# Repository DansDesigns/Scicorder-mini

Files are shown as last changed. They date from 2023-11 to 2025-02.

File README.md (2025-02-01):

# Ultra-Slim-Tricorder
A multi sensor device based on ESP32, Inspired by Star Trek TNG Tricorder

NOTE, DUE TO TECHNICAL LIMITATIONS, THIS PROJECT HAS BEEN UPGRADED - SEE THE SCIO REPO

Youtube Development Channel:
https://www.youtube.com/channel/UC_F5HQEmCyoRnEubfEMa24g

No copyright infringment intended, this is purely an exercise in fun and an homage to some great Sci-Fi Technology!

Hardware:
```
ESP32-WROOM-32e
NS8002 Amplifier Module
8ohm 1Watt Speaker
Wireless Charging with internal TP4056 LiPo Charger
MPR121 12-Channel Capacitive Touch Sensor
Red/Green Power Status LED
Tricolour Status LED's

Integrated Sensors:
INMP441 I2S Mono Microphone
VL53L0X ToF Laser Distance Sensor
HMC5883L Magnetometer
BME280 Environmental Temperature, Humidity, Pressure & Altitude Sensor
SI1145 Visible Light, UV & IR Sensor
LTR-3900-UV UVA & UVB Sensor
TCS3200 RGB Colour Sensor
MPU6050 3-Axis Accelerometer, 3-Axis Gyroscope
  & Internal Temperature Sensor all-in-one
Magnetic Open-Close Lid Sensor
microSD Card Slot for Data Logging
Custom Dust/Particle Density Sensor

3D Printed Case featuring Electroplated Gold Capacitive Buttons & Highlights.
```

## Hardware Setup
```

```

## Code & Libraries
```

Arduino Tones library is used to generate the different notification sounds.

Capacitive Touch is powered by the MPR121 chip aswell as using the ESP32's onboard Capacitive Touch Pins

I2S Microphone Streaming was modified from here:
- https://github.com/pschatzmann/arduino-audio-tools/tree/main

Wifi Manager was taken from here:
- https://github.com/ozbotics/WIFIMANAGER-ESP32/tree/master

OTA Updater modified from:
- https://www.youtube.com/watch?v=o4Qw0CDzO7E

```

## Installation
```
If building yourself, Flash the OTA_Installer.ino to the ESP32 via Arduino IDE.

On reboot the OTA Updater will search GitHub for the latest Release,
it automatically Downloads, Installs and Reboots the Tricorder.

Wifi will then need to be setup again by using the Setup_AP Function.
- RETAIN SSID BETWEEN UPDATES - WIP

Manual checking for update is possible by typing "U" into the Serial Monitor.

If need to change WIFI SSID, press the WIFI Button and connect to the
"Setup_AP" WIFI Access Point from a wifi enabled device, following the on screen instructions.
```

## Usage
```

```

## ToDo
```
WIP = In Progress, TBS = To Be Started , TBD = To Be Decided, R&D = Research needed

- Make simple OTA_Installer.ino starter file to run OTA updater, pulling latest Release to flash full working code. - DONE
- Finish this ReadMe..

```

```
## Contributing

Pull requests are welcome. For major changes, please open an issue first
to discuss what you would like to change.

Please make sure to update tests as appropriate.

```

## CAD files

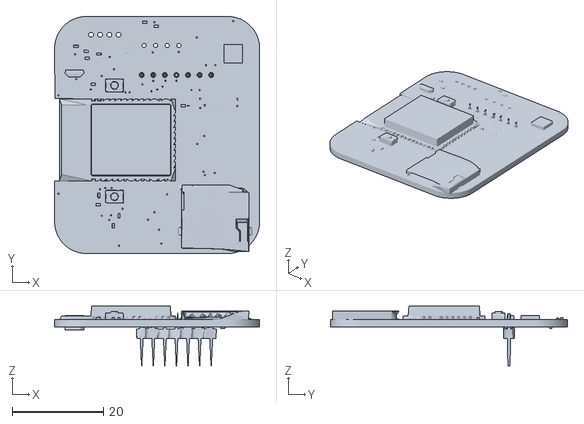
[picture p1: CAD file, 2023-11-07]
!_Prototype PCB 3D Files_!/UST-Main-Board.stl
45.0 x 52.0 x 13.1

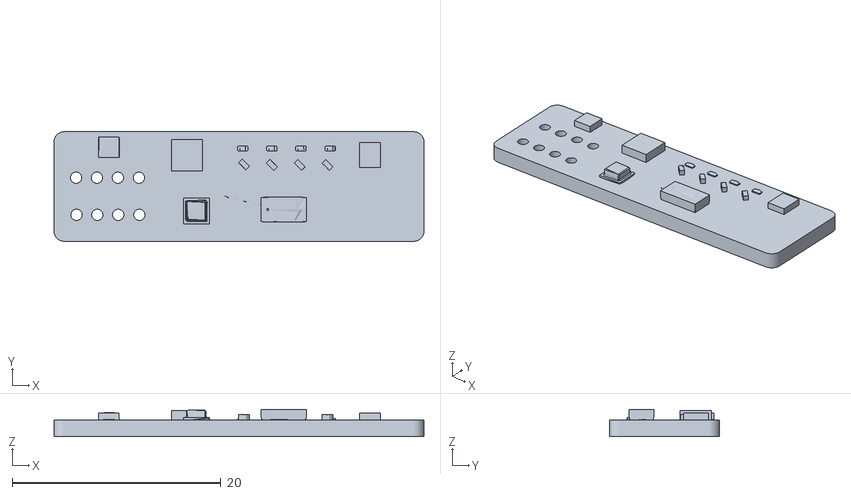
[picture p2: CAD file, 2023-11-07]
!_Prototype PCB 3D Files_!/UST-Sensor-Board.stl
35.5 x 10.5 x 2.61

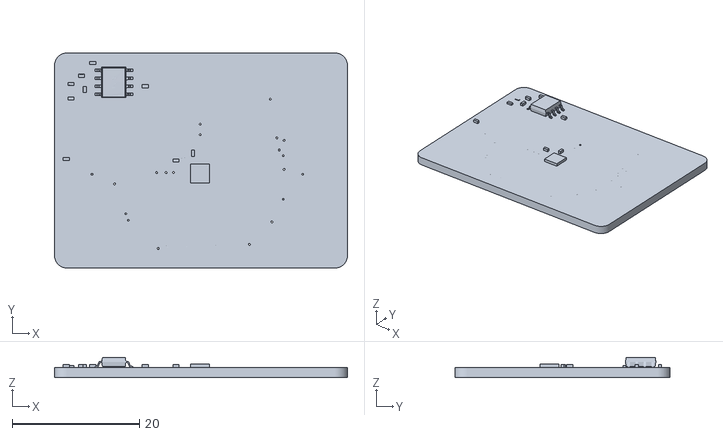
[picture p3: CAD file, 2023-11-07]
!_Prototype PCB 3D Files_!/UST-Battery_Input-Board.stl
46.1 x 33.9 x 3.22

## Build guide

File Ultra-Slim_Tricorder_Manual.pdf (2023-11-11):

# Ultra-Slim Tricorder

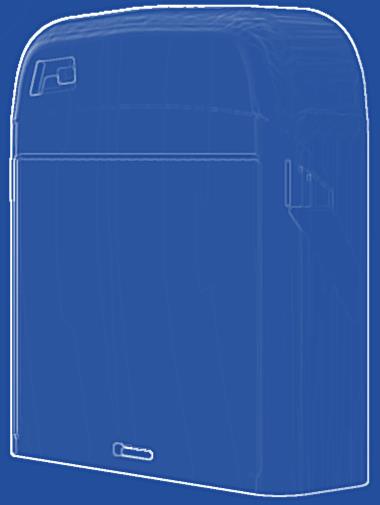
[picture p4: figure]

### DansDesigns

V0.1a

Sensor Board

Capacitive TouchPad
& Power

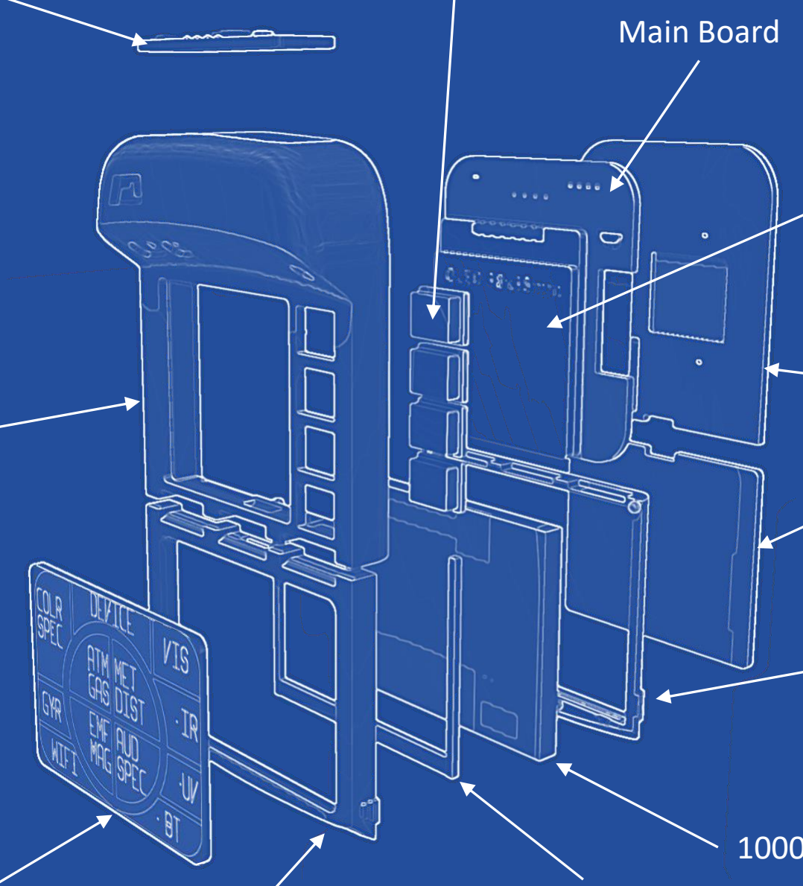
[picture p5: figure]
Main Board

Management Board | TouchPad Bracket

1000mAh LiPo

Lower Body
Rear Section

Lower Body
Forward Section

Upper Body
Main Section

1.5” Full
Colour OLED

Rear Covers

Capacitive Touch Buttons

# Exploded View

54.7mm

# Dimensions

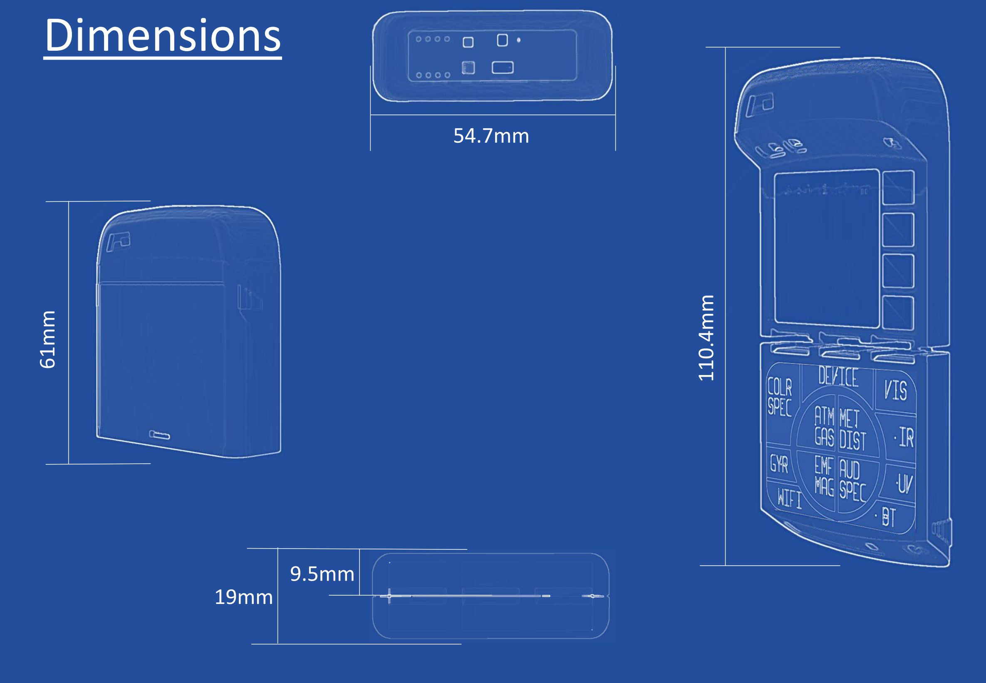
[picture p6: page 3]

19mm

61mm

9.5mm

110.4mm

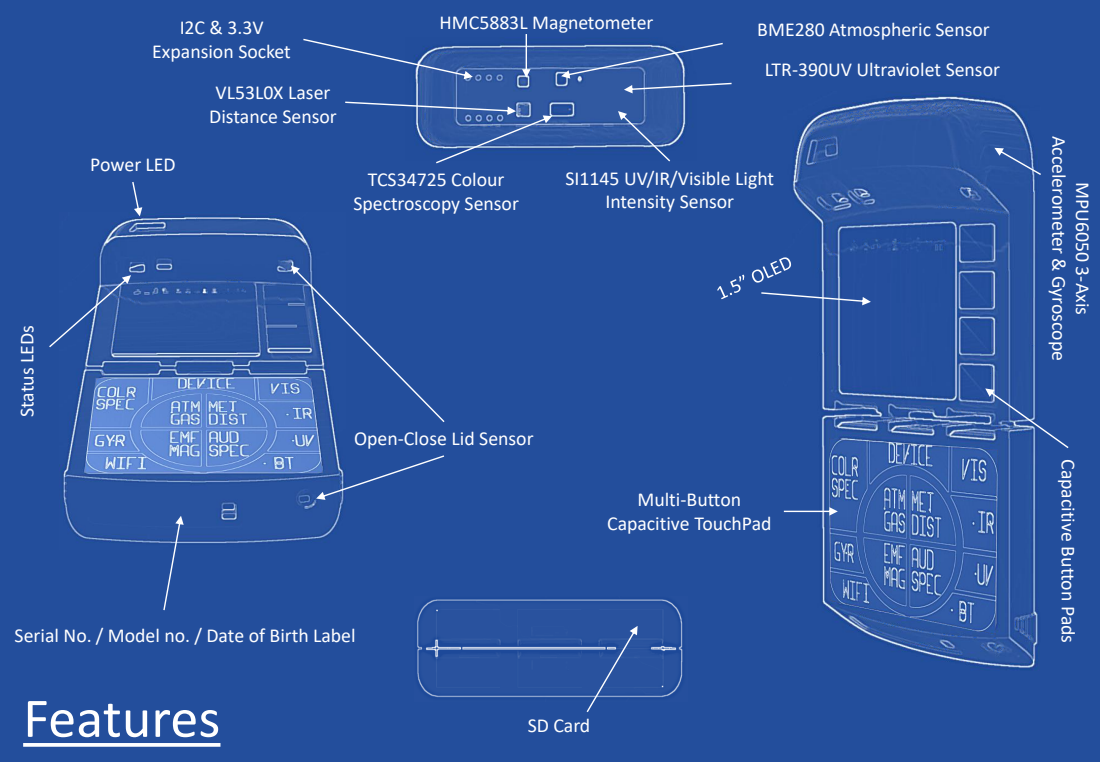
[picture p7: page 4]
I2C & 3.3V Expansion Socket; VL53L0X Laser Distance Sensor; HMC5883L Magnetometer; TCS34725 Colour Spectroscopy Sensor; Multi-Button Capacitive TouchPad; SD Card; Power LED; BME280 Atmospheric Sensor; Status LEDs; MPU6050 3-Axis; Accelerometer & Gyroscope

LTR-390UV Ultraviolet Sensor

SI1145 UV/IR/Visible Light
Intensity Sensor

Open-Close Lid Sensor

Capacitive Button Pads

Serial No. / Model no. / Date of Birth Label
Features

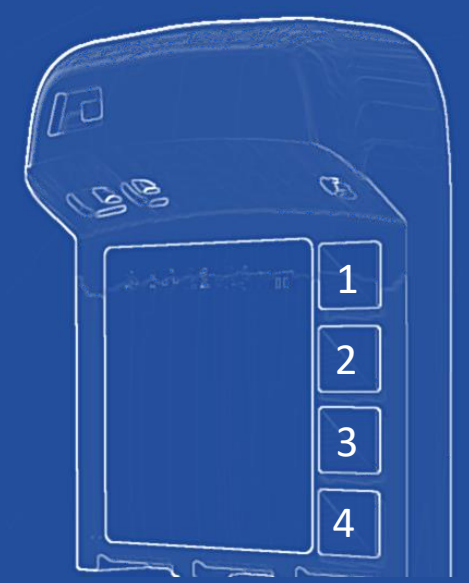
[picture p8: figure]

Mpr121 pin - | Lower TouchPad | - | Functions:
9 | - | COLR SPEC | - | Colour Spectroscopy
8 | - | GYR | - | Gyroscope/Accelerometer
6 | - | WiFi | - | WiFi toggle
10 | - | DEVICE | - | About/Device Specs, storage used/free etc
11 | - | ATM GAS | - | Temperature, Humidity, Pressure, Altitude & Gas
0 | - | MET DIST | - | Metric Laser Distance Meter
7 | - | EMF MAG | - | Magnetic field/Compass (Multi-Page)
1 | - | AUD SPEC | - | Audio Spectrum
2 | - | VIS | - | Visible Light/Colour Spectroscopy (Multi-Page)
3 | - | IR | - | Infrared Radiation
4 | - | UV | - | Ultraviolet Radiation
5 | - | BT | - | Bluetooth toggle

Upper Touch Buttons
Main-Functions:

1 - Next Page in same sensor group
2 - scan frequency toggle: 333ms/3 seconds /10 seconds/1 min
3 - begin/stop record data for 5 seconds? / single data log?
4 - memory playback for selected mode, -SEE MEMORY FUNCTIONS

MEMORY - FUNCTIONS:

1 | - next entry
2 | - previous entry
3 | - delete entry
4 | - exit memory playback

# Functions

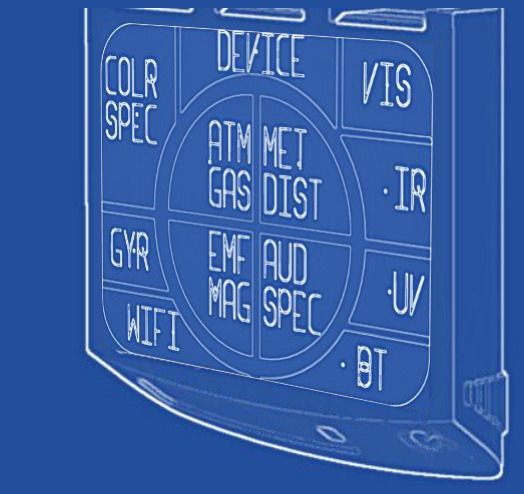
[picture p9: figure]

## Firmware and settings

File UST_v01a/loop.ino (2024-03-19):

void loop()
{
  unsigned long currentTime = millis();   // timer function for page update
  currtouched = cap.touched();        //Call first thing to read from MPR121
  up = touchRead(T4);// UP - 33
  back = touchRead(T5);// BACK - 12
  down = touchRead(T8);// DOWN - 13
  enter = touchRead(T7);// ENTER - 27


  // Check for Sleep state:
  if (EXT0_wake_Pin == HIGH)
  {
    esp_sleep_enable_ext0_wakeup(GPIO_NUM_35,0); //1 = High, 0 = Low
    esp_deep_sleep_start();
    // Serial.println("This will never be printed");
  }

  else if (EXT0_wake_Pin == LOW)
  {
    // lights on here..
    // power on things here?
  }
  
  // UI Elements:

  // Battery:
  //imgbatt.createSprite(30, 12);       // Creates Sprite 1 in (size of sprite in pixels: W, H)
  imgstat.createSprite(128, 12);       // Creates Sprite 1 in (size of sprite in pixels: W, H)
  imgstat.fillRect(0, 0, 128, 12, BLACK);    // Clear Statusbar
  imgstat.drawBitmap( 98, 1, image_Battery, 26, 8, GREY);
  if (BattLevel < 14)
  {
    imgstat.fillRect(100, 3, 4, 4, RED);    // Battery 0-10% - set red when here
    imgstat.fillRect(105, 3, 5, 4, GREY);    // Battery 11-35% - set orange when here & set grey when lower than this
    imgstat.fillRect(111, 3, 5, 4, GREY);    // Battery 36-75% - set grey when lower than this
    imgstat.fillRect(117, 3, 3, 4, GREY);    // Battery 75-100% - set grey when lower than this
  }
  else if ((BattLevel > 15) && (BattLevel < 34))
  {
    imgstat.fillRect(100, 3, 4, 4, ORANGE);    // Battery 0-10% - set red when here
    imgstat.fillRect(105, 3, 5, 4, GREY);    // Battery 11-35% - set orange when here & set grey when lower than this
    imgstat.fillRect(111, 3, 5, 4, GREY);    // Battery 36-75% - set grey when lower than this
    imgstat.fillRect(117, 3, 3, 4, GREY);    // Battery 75-100% - set grey when lower than this
  }
  else if ((BattLevel > 35) && (BattLevel < 49))
  {
    imgstat.fillRect(100, 3, 4, 4, ORANGE);    // Battery 0-10% - set red when here
    imgstat.fillRect(105, 3, 5, 4, ORANGE);    // Battery 11-35% - set orange when here & set grey when lower than this
    imgstat.fillRect(111, 3, 5, 4, GREY);    // Battery 36-75% - set grey when lower than this
    imgstat.fillRect(117, 3, 3, 4, GREY);    // Battery 75-100% - set grey when lower than this
  }
  else if ((BattLevel > 50) && (BattLevel < 75))
  {
    imgstat.fillRect(100, 3, 4, 4, GREEN);    // Battery 0-10% - set red when here
    imgstat.fillRect(105, 3, 5, 4, GREEN);    // Battery 11-35% - set orange when here & set grey when lower than this
    imgstat.fillRect(111, 3, 5, 4, GREEN);    // Battery 36-75% - set grey when lower than this
    imgstat.fillRect(117, 3, 3, 4, GREY);    // Battery 75-100% - set grey when lower than this
  }
  else if (BattLevel > 76)
  {
    imgstat.fillRect(100, 3, 4, 4, GREEN);    // Battery 0-10% - set red when here
    imgstat.fillRect(105, 3, 5, 4, GREEN);    // Battery 11-35% - set orange when here & set grey when lower than this
    imgstat.fillRect(111, 3, 5, 4, GREEN);    // Battery 36-75% - set grey when lower than this
    imgstat.fillRect(117, 3, 3, 4, GREEN);    // Battery 75-100% - set grey when lower than this
  }
  //delay(50);
  //imgbatt.pushSprite(98, 0);

  // WIFI, BT & SD card Status:

  // WIFI:
  if (wifi_state == WL_CONNECTED)
  {
    //tft.drawBitmap( 0, 1, image_wifi, 10, 10, AZURE);
    imgstat.drawBitmap( 0, 1, image_wifi, 10, 10, GREEN);
  }
  else if (wifi_state == WL_DISCONNECTED)
  {
    imgstat.drawBitmap( 0, 1, image_wifi, 10, 10, RED);
  }
  else if (wifi_state == WL_CONNECTION_LOST)
  {
    imgstat.drawBitmap( 0, 1, image_wifi, 10, 10, ORANGE);
  }
  else
  {
    imgstat.drawBitmap( 0, 1, image_wifi, 10, 10, GREY);
  }

  // BT:
  if (bt_state == true) {
    imgstat.drawBitmap( 13, 1, image_Bluetooth, 5, 8, BLUE);
  }
  else if (bt_state == false)
  {
    imgstat.drawBitmap( 13, 1, image_Bluetooth, 5, 8, GREY);
  }

  // SD Card:
  if (sd_state == true)
  {
    imgstat.drawBitmap( 22, 1, image_SDcardMounted, 11, 8, TURQUOISE);
  }
  else if (sd_state == false)
  {
    imgstat.drawBitmap( 22, 1, image_SDcardFail, 11, 8, GREY);
  }
  delay(200);
  imgstat.pushSprite(0, 0);


  /*

    // Internal TouchPad - Multi Function:
    if (up < threshold) {      //  ~~~~~~~ Internal Touch 1 - SCAN MODE TOGGLE ~~~~~~~
      Serial.println("T1 Touched");
      //ButtonTone(Tones);
      scan_counter++;      // needed for multi-function mode
    }

    if (scan_counter == 0) {       //  ~~~~~~~ multi-function first tap ~~~~~~~
      //  1st function
      eventInterval = 400;       // Screen Update Interval
    }


    if (scan_counter == 1) {       //  ~~~~~~~ multi-function second tap ~~~~~~~
      // 2nd function
      eventInterval = 1000;       // Screen Update Interval
    }

    if (scan_counter > 1) {      //  ~~~~~~~ Over-tap protection or replace ">" with "==" to make third tap function ~~~~~~~
      // 3rd function
      scan_counter = 0;  // comment out it ofther functions than off
    }

    // ~~~~~~~~~~ Internal TouchPads: ~~~~~~~~~~
    if (up < threshold) {          //  ~~~~~~~ Internal Touch 1 - Up/Previous ~~~~~~~

    }

    if (back < threshold) {          //  ~~~~~~~ Internal Touch 2 - Enter/Select ~~~~~~~

    }

    if (down < threshold) {      //  ~~~~~~~ Internal Touch 3 - Back/Delete ~~~~~~~


    }

    if (enter < threshold) {      //  ~~~~~~~ Internal Touch 4 - Down/Next ~~~~~~~

    }


    if (back < threshold) {          //  ~~~~~~~ Internal Touch 2 - Data Logging ~~~~~~~
    Serial.println("T2 Touched");
    //ButtonTone(Tones);
    borders_close();
    delay(50);
    tft.setTextSize(1);
    tft.setTextColor(WHITE);
    tft.setCursor(35, 11);
    //tft.print("Mode-a");
    //scan_counter = 0;                 // reset screen update interval to default 333ms
    Mode = 'a';                         // Scan mode
    }

    if (down < threshold) {      //  ~~~~~~~ Internal Touch 3 ~~~~~~~
    Serial.println("T3 Touched");
    //ButtonTone(Tones);
    borders_close();
    delay(50);
    tft.setTextSize(1);
    tft.setTextColor(WHITE);
    tft.setCursor(35, 11);
    //tft.print("Mode-s");
    //scan_counter = 0;                 // reset screen update interval to default 333ms
    Mode = 's';                         // Scan mode

    }

    if (enter < threshold) {      //  ~~~~~~~ Internal Touch 4 ~~~~~~~
    Serial.println("T4 Touched");
    //ButtonTone(Tones);
    borders_close();
    delay(50);
    tft.setTextSize(1);
    tft.setTextColor(WHITE);
    tft.setCursor(35, 11);
    //tft.print("Rst Icons");
    //scan_counter = 0;                 // reset screen update interval to default 333ms
    Mode = 'i';                         // Scan mode
    sd_state = false;
    bt_state = false;
    wifi_state = false;
    BattLevel = 100;
    }

  */
  // MPR121 TouchPads:

  if (cap.touched() & (1 << 0))             // Button 0 - MET/DIST
  {
    ButtonTone();
    borders_close();
    delay(50);
    tft.setTextSize(1);
    tft.setTextColor(WHITE);
    tft.setCursor(35, 11);
    //tft.print("MET/DST");
    //scan_counter = 0;                 // reset screen update interval to default 333ms
    Mode = 'B';                         // Scan mode
  }


  if (cap.touched() & (1 << 1))             // Button 1 - AUD SPEC
  {
    ButtonTone();
    borders_close();
    delay(50);
    tft.setTextSize(1);
    tft.setTextColor(WHITE);
    tft.setCursor(35, 11);
    //tft.print("AUDSPC");
    //scan_counter = 0;                 // reset screen update interval to default 333ms
    Mode = 'A';                         // Scan mode
  }


  if (cap.touched() & (1 << 2))             // Button 2 - VIS
  {
    ButtonTone();
    borders_close();
    delay(50);
    tft.setTextSize(1);
    tft.setTextColor(WHITE);
    tft.setCursor(35, 11);
    //tft.print(" Visible");
    //scan_counter = 0;                 // reset screen update interval to default 333ms
    Mode = '2';                         // Scan mode
  }

  if (cap.touched() & (1 << 3))             // Button 3 - IR
  {
    //ButtonTone(Tones);
    borders_close();
    delay(50);
    tft.setTextSize(1);
    tft.setTextColor(WHITE);
    tft.setCursor(35, 11);
    //tft.print("    IR");
    //scan_counter = 0;                 // reset screen update interval to default 333ms
    Mode = '3';                         // Scan mode
  }

  if (cap.touched() & (1 << 4))             // Button 4 - UV
  {
    //ButtonTone(Tones);
    borders_close();
    delay(50);
    tft.setTextSize(1);
    tft.setTextColor(WHITE);
    tft.setCursor(35, 11);
    //tft.print("    UV");
    //scan_counter = 0;                 // reset screen update interval to default 333ms
    Mode = '4';                         // Scan mode
  }


  if (cap.touched() & (1 << 5))             // Button 5 - BT
  {
    //ButtonTone(Tones);
    borders_close();
    delay(50);
    tft.setTextSize(1);
    tft.setTextColor(WHITE);
    tft.setCursor(35, 11);
    //tft.print("    BT");
    //scan_counter = 0;                 // reset screen update interval to default 333ms
    Mode = '5';                         // Scan mode
  }


  if (cap.touched() & (1 << 6))             // Button 6 - WIFI
  {
    //ButtonTone(Tones);
    borders_close();
    delay(50);
    //tft.setTextSize(1);
    //tft.setTextColor(WHITE);
    //tft.setCursor(35, 11);
    //tft.print("   WIFI");
    //scan_counter = 0;                 // reset screen update interval to default 333ms
    Mode = '6';                         // Scan mode
  }


  if (cap.touched() & (1 << 7))             // Button 7 - EMF/MAG
  {
    //ButtonTone(Tones);
    borders_close();
    delay(50);
    tft.setTextSize(1);
    tft.setTextColor(WHITE);
    tft.setCursor(35, 11);
    //tft.print("EMF/MAG");
    //scan_counter = 0;                 // reset screen update interval to default 333ms
    Mode = '7';                         // Scan mode
  }


  if (cap.touched() & (1 << 8))             // Button 8 - GYR
  {
    //ButtonTone(Tones);
    borders_close();
    delay(50);
    tft.setTextSize(1);
    tft.setTextColor(WHITE);
    tft.setCursor(35, 11);
    //tft.print("   GYR");
    //scan_counter = 0;                 // reset screen update interval to default 333ms
    Mode = '8';                         // Scan mode
  }


  if (cap.touched() & (1 << 9))             // Button 9 - COLR SPEC
  {
    //ButtonTone(Tones);
    borders_close();
    delay(50);
    tft.setTextSize(1);
    tft.setTextColor(WHITE);
    tft.setCursor(35, 11);
    //tft.print("COLRSPC");
    //scan_counter = 0;                 // reset screen update interval to default 333ms
    Mode = '9';                         // Scan mode
  }

  if (cap.touched() & (1 << 10))             // Button 10 - DEVICE
  {
    //ButtonTone(Tones);
    borders_close();
    delay(50);
    tft.setTextSize(1);
    tft.setTextColor(WHITE);
    tft.setCursor(35, 11);
    //tft.print(" DEVICE");
    //scan_counter = 0;                 // reset screen update interval to default 333ms
    Mode = 'A';                         // Scan mode
  }

  if (cap.touched() & (1 << 11))             // Button 11 - ATM/GAS
  {
    //ButtonTone(Tones);
    borders_close();
    delay(50);
    tft.setTextSize(1);
    tft.setTextColor(WHITE);
    tft.setCursor(35, 11);
    //tft.print("ATM/GAS");
    //scan_counter = 0;                 // reset screen update interval to default 333ms
    Mode = 'B';                         // Scan mode
  }


  lasttouched = currtouched;


  // ~~~~~~~~~~~~~~~~~~~~~~~~~ Wake from Sleep Reason and Reaction: ~~~~~~~~~~~~~~~~~~~~~~~~~
  esp_sleep_wakeup_cause_t wakeup_reason;
  wakeup_reason = esp_sleep_get_wakeup_cause();
  switch (wakeup_reason) {
    case ESP_SLEEP_WAKEUP_EXT0 : Serial.print("wake_from_ext0()") ; break;
    case ESP_SLEEP_WAKEUP_TOUCHPAD : Serial.println("TouchPad WakeUp Cause"); break;
    case ESP_SLEEP_WAKEUP_TIMER : callback(); break;
    case ESP_SLEEP_WAKEUP_ULP : callback() ; break;
    case ESP_SLEEP_WAKEUP_UNDEFINED : callback() ; break;
    case ESP_SLEEP_WAKEUP_ALL : callback() ; break;
    case ESP_SLEEP_WAKEUP_EXT1 : callback() ; break;
    case ESP_SLEEP_WAKEUP_GPIO : callback() ; break;
    case ESP_SLEEP_WAKEUP_UART : callback() ; break;
    case ESP_SLEEP_WAKEUP_WIFI : callback() ; break;
    case ESP_SLEEP_WAKEUP_BT : callback() ; break;
    case ESP_SLEEP_WAKEUP_COCPU : Serial.println("COCPU WakeUp Cause") ; break;
    case ESP_SLEEP_WAKEUP_COCPU_TRAP_TRIG : Serial.println("COCPU_TRAP_TRIG WakeUp Cause") ; break;
      //    case ESP_SLEEP_WAKEUP_UNDEFINED : Serial.println("UNKNOWN WakeUp Cause") ; break;
  }


  switch (Mode)
  {
    case 'a':
      // ~~~~~~~ sleepmode ~~~~~~~
      //lightSleep();
      tft.setTextColor(GREEN);
      tft.setCursor(28, 63);
      tft.print("Ready");

      if (up < threshold) {      //  ~~~~~~~ Internal Touch 1 - SCAN MODE TOGGLE ~~~~~~~
        Serial.println("T1 Touched");
        //ButtonTone(Tones);
        tft.fillRect(28, 50, 50, 20, BLACK);        // clear content text is 11 pixels high (actually -x from point of reference)
        scan_counter++;      // needed for multi-function mode
      }
      break;


    case 'b':
      // ~~~~~~~ I2C Scanner ~~~~~~~
      //i2c_scanner();
      tft.setTextColor(GREEN);
      tft.setCursor(28, 63);
      tft.print("Steady");

      if (up < threshold) {      //  ~~~~~~~ Internal Touch 1 - SCAN MODE TOGGLE ~~~~~~~
        Serial.println("T1 Touched");
        //ButtonTone(Tones);
        tft.fillRect(28, 50, 50, 20, BLACK);        // clear content text is 11 pixels high (actually -x from point of reference)
        scan_counter++;      // needed for multi-function mode
      }
      break;


    case 'c':
      tft.setTextColor(GREEN);
      tft.setCursor(28, 63);
      tft.print("Go!");
      if (up < threshold) {      //  ~~~~~~~ Internal Touch 1 - SCAN MODE TOGGLE ~~~~~~~
        Serial.println("T1 Touched");
        //ButtonTone(Tones);
        tft.fillRect(28, 50, 50, 20, BLACK);        // clear content text is 11 pixels high (actually -x from point of reference)
        scan_counter++;      // needed for multi-function mode
      }

      if (currentTime - previousTime >= eventInterval)
      {
        //EMPTY
        //tft.fillRect(28, 63, 50, 15, BLACK);        // clear content
        //tft.setCursor(28, 63);
        //tft.print("scan !");
      }
      previousTime = currentTime;           // Called after Sprite

      break;

    case 's':
      // ~~~~~~~ sleepmode ~~~~~~~
      //lightSleep();
      tft.setTextColor(GREEN);
      tft.setCursor(28, 63);
      tft.print("Mode s");
      break;

    case 'i':
      // ~~~~~~~ sleepmode ~~~~~~~
      tft.setTextColor(GREEN);
      tft.setCursor(28, 63);
      tft.print("Reset Icons");
      BattLevel = 100;
      break;

    case '0':
      // ~~~~~~~ MET/DIST ~~~~~~~
      tft.setTextColor(GREEN);
      tft.setCursor(28, 63);
      tft.print("MET/DIST");
      sd_state = true;
      BattLevel = 65;
      break;

    case '1':
      // ~~~~~~~ AUD SPEC ~~~~~~~
      tft.setTextColor(GREEN);
      tft.setCursor(28, 63);
      tft.print("AUD SPEC");
      wifi_state = true;
      BattLevel = 44;
      break;

    case '2':
      // ~~~~~~~ VIS ~~~~~~~
      tft.setTextColor(GREEN);
      tft.setCursor(28, 63);
      tft.print("VIS");
      bt_state = true;
      BattLevel = 8;
      break;

    case '3':
      // ~~~~~~~ IR ~~~~~~~
      tft.setTextColor(GREEN);
      tft.setCursor(28, 63);
      tft.print("IR");
      break;

    case '4':
      // ~~~~~~~ UV ~~~~~~~
      tft.setTextColor(GREEN);
      tft.setCursor(28, 63);
      tft.print("UV");
      break;

    case '5':
      // ~~~~~~~ BT ~~~~~~~
      tft.setTextColor(GREEN);
      tft.setCursor(28, 63);
      //tft.print("BT");
      bt_menu();
      break;

    case '6':
      // ~~~~~~~ WIFI ~~~~~~~
      //tft.setTextColor(GREEN);
      //tft.setCursor(28, 63);
      //tft.print("WIFI");
      wifi_menu();
      break;

    case '7':
      // ~~~~~~~ EMF/MAG ~~~~~~~
      tft.setTextColor(GREEN);
      tft.setCursor(28, 63);
      tft.print("EMF/MAG");
      break;

    case '8':
      // ~~~~~~~ GYR ~~~~~~~
      tft.setTextColor(GREEN);
      tft.setCursor(28, 63);
      tft.print("GYR");
      break;

    case '9':
      // ~~~~~~~ COLR SPEC ~~~~~~~
      tft.setTextColor(GREEN);
      tft.setCursor(28, 63);
      tft.print("COLR SPEC");
      break;

    case 'A':
      // ~~~~~~~ DEVICE ~~~~~~~
      //tft.setTextColor(GREEN);
      //tft.setCursor(28, 63);
      //tft.print("DEVICE");
      //tft.fillRect(0, 12, 128, 128, BLACK);        // clear screen except Statusbar


      break;

    case 'B':
      // ~~~~~~~ ATM/GAS ~~~~~~~
      atm_gas();
      break;


  }
}

//EOF

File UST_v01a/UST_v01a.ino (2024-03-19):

/*
        UST - Ultra-Slim Tricorder - V0.1a

        Software:
                  - GUI: TFT_eSPI
        Hardware:
                  -

*/


// Libraries:

// File System & File Browser:
#include "FS.h"
#include <LittleFS.h>
#include <EEPROM.h>
//#include <SD_MMC.h>
//#include <SD.h>
#include <ESPxWebFlMgr.h>

// System Hardware:
#include <SPI.h>
#include <Wire.h>
#include <Arduino.h>
#include <SoftwareSerial.h>
#include <Adafruit_MPR121.h>            // Capacitive Touch Sensor @ 0x5A
//#include "Arduino-MAX17055_Driver.h"    // Battery monitor

// Wifi:
#include <WiFi.h>
#include "WebServer.h"    //https://github.com/zhouhan0126/WebServer-esp32
#include "DNSServer.h"    //https://github.com/zhouhan0126/DNSServer---esp32
#include <HTTPClient.h>
#include <HTTPUpdate.h>
#include <WiFiClientSecure.h>
#include <WiFiManager.h>  //https://github.com/ozbotics/WIFIMANAGER-ESP32
#include "ArduinoJson.h"  //https://github.com/bblanchon/ArduinoJson
#include "cert.h"

// Graphics:

//      TFT_eSPI
#include "TFT_eSPI.h"
// Included Fonts:
#include "TimeBurner12.h"
#define timeburner12 TimeBurner12
#include "Aspergit.h"
#define aspergit18 Aspergit
#include "NotoSansBold15.h"
#define SansBold15 NotoSansBold15
#include "Trench35.h"
#define trench35 Trench35
#include "Trench28.h"
#define trench28 Trench28


//    Adafruit_GFX
//#include "Adafruit_GFX.h"               // Core graphics library
//#include "Adafruit_SSD1351.h"           // 1.5" OLED library
// Included Fonts:
//#include "Whipsmart_XMvZ8pt7b.h"
//#include <Fonts/FreeSans12pt7b.h>

// Audio:
#include <DacESP32.h>


// Sensors:
#include <Adafruit_Sensor.h>
#include <Seeed_BME280.h>               // BME280 Temperature, Humidity, Pressure Sensor @ 0x76
//#include <VL53L0X.h>                    // IR Time-of-Flight Distance Sensor @ 0x29
//#include <LTR390.h>                     // UV Sensor
//#include <MPU6050_tockn.h>              // Gryoscopic Accelerometer
//#include "Adafruit_HMC5883_U.h"         // GY-271 Magnetometer

// Deffinitions:
// TouchPins:
#define touchPin T7   // GPIO27   enter IntTouch1 
#define touchPin T4   // GPIO33   up    IntTouch4 
#define touchPin T5   // GPIO12   back  IntTouch2 
#define touchPin T8   // GPIO13   down  IntTouch3 

// I2S:
#define I2S_WS 15
#define I2S_SD 32
#define I2S_SCK 14

// DAC:
//#define DAC1 25
DacESP32 dac1(GPIO_NUM_25);
#define ns8002_mute 2
//#define Tones 26
#define EXT0_wake_Pin 35

// I2C:
// SDA 21 (42)
// SCL 22 (39)
#define ltr390_I2C_ADDRESS 0x53
#define BME280_ADDRESS   0x76

// UART:
// Serial0: RX0 on GPIO3, TX0 on GPIO1

//SPI OLED:
// Screen setup done in libraries/TFT_eSPI/User_Setup.h
// Pins referenced here & in "About" file..
//#define _sclk 18
//#define _mosi 23
//#define _dc   16
//#define _cs   17
//#define _rst  5


// Screen dimensions
#define SCREEN_WIDTH  128
#define SCREEN_HEIGHT 128

// SPI microSD card:
#define sd_sclk 18
#define sd_mosi 23
#define sd_miso 19
#define sd_dc   16
#define sd_rst  5
#define sd_cs   4


// Colour Conversion from RGB to HEX:
#define RGB(r, g, b) (((r&0xF8)<<8)|((g&0xFC)<<3)|(b>>3))
// Colour definitions:
#define BLACK     RGB (0, 0, 0)
#define WHITE     RGB(255,255,255)
#define GREY      RGB(127, 127, 127)
#define DARKGREY  RGB(64, 64, 64)
#define TURQUOISE RGB(0, 128, 128)
#define PINK      RGB(255, 128, 192)
#define PINKRED   RGB(235, 158, 220)
#define OLIVE     RGB(128, 128, 0)
#define PURPLE    RGB(128, 0, 128)
#define AZURE     RGB(0, 128, 255)
#define ORANGE    RGB(255,136,0)
#define YELLOW    RGB(255,255,0)
#define GREEN      RGB(51,255,51)
#define SKYBLUE   RGB(135,206,235)
#define BLUE      RGB(0,0,255)
#define BLUEVIOLET RGB(138,43,226)
#define AQUAMARINE RGB(127,255,212)
#define RED        RGB(255,53,0)
#define DARKRED    RGB(193,0,0)
#define HONEY      RGB(255,204,153)
#define BUTTER     RGB(255,238,204)
#define OCTSUNSET  RGB(255,68,0)
#define WARNING    RGB(255,88,20)
#define BACKGROUND RGB(56,32,32)


// ~~~~~~~~~~~~~~~~~~~~~~~~~~FIRMWARE VERSION~~~~~~~~~~~~~~~~~~~~~~~~~~~~~~
// Current Version to compare to Server Version (!) 0.1 for base testing(!)
String FirmwareVer = "0.2";
//{
//    "0.1"
//};
// ~~~~~~~~~~~~~~~~~~~~~~~~~~~~~~~~~~~~~~~~~~~~~~~~~~~~~~~~~~~~~~~~~~~~~~~~

// Initillizations & Variables:

Adafruit_MPR121 cap = Adafruit_MPR121();      // Capacitive Sensor
BME280 bme280;
//VL53L0X tof;
//LTR390 ltr390(ltr390_I2C_ADDRESS);
//MPU6050 mpu6050(Wire);
//Adafruit_HMC5883_Unified mag = Adafruit_HMC5883_Unified(12345);

const char* ssid = "Default SSID";
const char* passphrase = "Default passord";

const word filemanagerport = 8080;

ESPxWebFlMgr filemgr(filemanagerport); // we want a different port than the webserver

//bools, chars, consts, floats, ints etc:
bool bt_state = false;
bool wifi_state = WiFi.status();
bool sd_state = false;
float BattLevel;
char Mode = 'z';
int scan_counter = 0;       // Scan Frequency Toggle Counter
float pressure;
float Altitude;
unsigned long eventInterval = 500;       // Screen Update Interval
unsigned long previousTime = 0;
unsigned long currentTime = millis();   // timer function for page update
int i = 0;
int statusCode;
String st;
String content;
String esid;
String epass = "";

//Function Decalrations
bool testWifi(void);
void launchWeb(void);
void setupAP(void);

//Establishing Local server at port 80
WebServer server(80);

//Touch Settings (Internal):
const int threshold = 40 ;
int up;
int back;
int down;
int enter;

//Touch Settings (MPR121):
uint16_t lasttouched = 0;
uint16_t currtouched = 0;
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
